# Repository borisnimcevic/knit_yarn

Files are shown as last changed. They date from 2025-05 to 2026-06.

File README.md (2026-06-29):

# Knit & Yarn Badge

A round PCB badge shaped like a ball of yarn with knitting needles. Six LEDs shine through the board face-down, lighting up the design from behind. Powered by a CR2032 coin cell; the brooch pin doubles as the power switch.

assembled badge

Designed in KiCad. Three badge variants and one SAO variant are included.

---

## Versions

| Folder | Description |
|---|---|
| `knit_yarn_badge_v1` | First prototype — through-hole battery holder |
| `knit_yarn_badge_v2` | SMD redesign, improved layout |
| `knit_yarn_badge_v3` | Current version — 0805 components, no vias |
| `knit_yarn_SAO` | Simple Add-On variant with 2×2 header |

---

## Bill of Materials (per badge)

| Reference | Component | Package | Qty |
|---|---|---|-----|
| D1–D6 | LED (any color) | 0805 | 6 |
| R1–R6 | Resistor | 0805 | 6 |
| BT1 | CR2032 coin cell holder | THT | 1 |
| SW1 | Brooch pin / SPST switch | custom | 1 |

> **Note:** Resistor values depend on your LED choice. For a standard 2V LED with a 3V CR2032 at ~10 mA per LED: R = (3V − 2V) / 10 mA = **100 Ω**.

---

## Ordering

Ready-to-order Gerber zips are in the [`order/`](./order/) folder:

- [`order/knit_yarn_badge_v1.zip`](./order/knit_yarn_badge_v1.zip)
- [`order/knit_yarn_badge_v2.zip`](./order/knit_yarn_badge_v2.zip)
- [`order/knit_yarn_badge_v3.zip`](./order/knit_yarn_badge_v3.zip) ← recommended
- [`order/knit_yarn_SAO.zip`](./order/knit_yarn_SAO.zip)

Upload the zip directly to your PCB fab (JLCPCB, PCBWay, etc.).

---

## Assembly

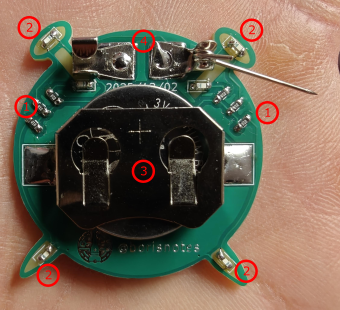
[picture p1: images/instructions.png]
instructions


1. **Resistors** — solder all 6 first (they're the lowest-profile component)
2. **LEDs** — place them **face down** (they shine into the PCB, not away from it)
   - The green mark on the LED points to the cathode, which aligns with the white edge on the footprint

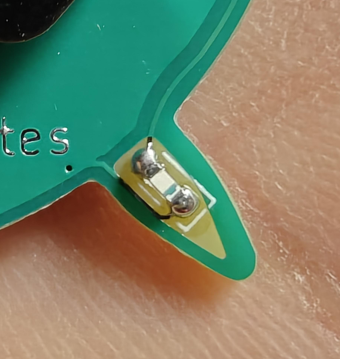
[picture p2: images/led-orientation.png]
led orientation
   

3. **Battery holder** — battery inserts from the back
4. **Brooch pin** — two-part assembly; use enough solder on both pads or the tension from clipping it may pop it loose

---

## SVG Source Files

The artwork SVGs used to generate the board graphics live in [`svg_source/`](./svg_source/).

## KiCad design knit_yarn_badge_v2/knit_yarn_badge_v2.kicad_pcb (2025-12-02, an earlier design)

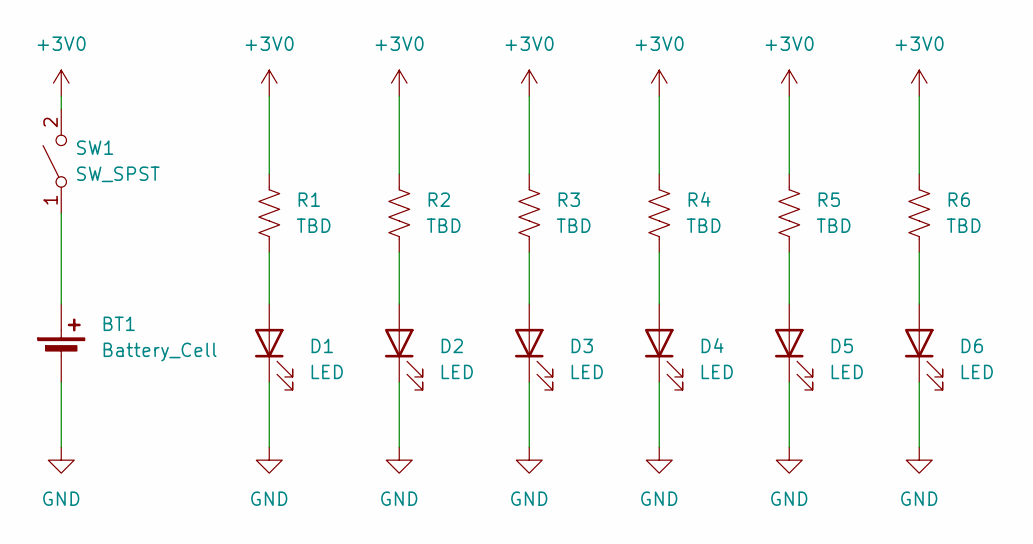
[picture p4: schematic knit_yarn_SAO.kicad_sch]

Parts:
BT1: Battery_Cell; BatteryHolder_Keystone_3002_1x2032
D1, D2, D3, D4, D5, D6: LED; LED_0603_1608Metric_Pad1.05x0.95mm_HandSolder
R1, R2, R3, R4, R5, R6: TBD; R_0603_1608Metric_Pad0.98x0.95mm_HandSolder
SW1: SW_SPST; brooch_SW_20mm

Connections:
+3V0: R1.1, R2.1, R3.1, R4.1, R5.1, R6.1, SW1.2 (B)
GND: BT1.2 (-), D1.1 (K), D2.1 (K), D3.1 (K), D4.1 (K), D5.1 (K), D6.1 (K)
unnamed: BT1.1 (+), SW1.1 (A)
unnamed: D1.2 (A), R1.2
unnamed: D2.2 (A), R2.2
unnamed: D3.2 (A), R3.2
unnamed: D4.2 (A), R4.2
unnamed: D5.2 (A), R5.2
unnamed: D6.2 (A), R6.2


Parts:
BT1: Battery_Cell; BatteryHolder_Keystone_3002_1x2032
D1, D2, D3, D4, D5, D6: LED; LED_0805_2012Metric_Pad1.15x1.40mm_HandSolder
R1, R2, R3, R4, R5, R6: TBD; R_0805_2012Metric_Pad1.20x1.40mm_HandSolder
SW1: SW_SPST; brooch_SW_20mm

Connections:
+3V0: R1.1, R2.1, R3.1, R4.1, R5.1, R6.1, SW1.2 (B)
GND: BT1.2 (-), D1.1 (K), D2.1 (K), D3.1 (K), D4.1 (K), D5.1 (K), D6.1 (K)
unnamed: BT1.1 (+), SW1.1 (A)
unnamed: D1.2 (A), R1.2
unnamed: D2.2 (A), R2.2
unnamed: D3.2 (A), R3.2
unnamed: D4.2 (A), R4.2
unnamed: D5.2 (A), R5.2
unnamed: D6.2 (A), R6.2

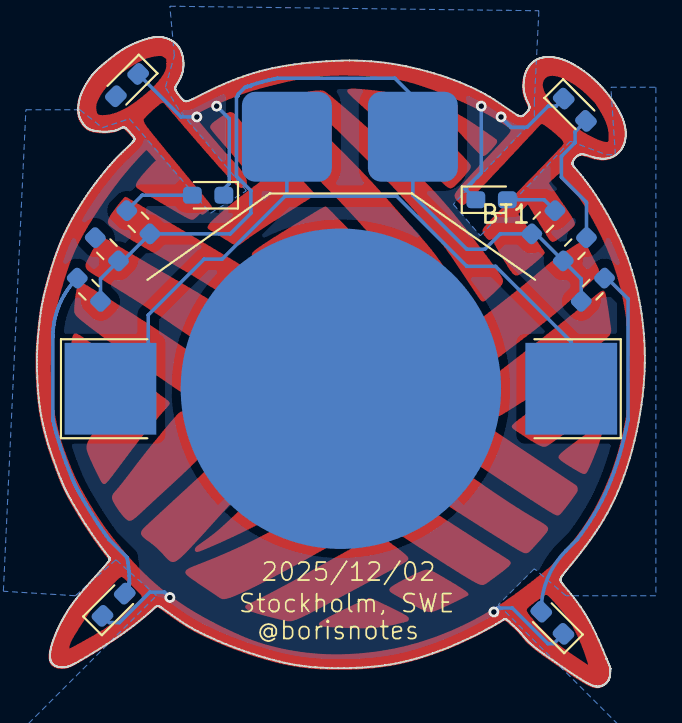
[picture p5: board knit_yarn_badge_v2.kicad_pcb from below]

Board: 2 copper layers, 33.8 x 36.1 mm, 14 parts (14 on the bottom side), 9 nets.

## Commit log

2025-05-12 Init repo.
    [knit_yarn.kicad_pcb, knit_yarn.kicad_sch]
2025-05-12 happy with graphics and added two more LEDs
    [knit_yarn.kicad_pcb, knit_yarn.kicad_sch]
2025-05-12 components in place
    [knit_yarn.kicad_pcb]
2025-05-12 back pour area
    [knit_yarn.kicad_pcb]
2025-05-12 fist draft
    [knit_yarn.kicad_pcb]
2025-05-12 one via
    [knit_yarn.kicad_pcb]
2025-05-12 add silk screen
    [knit_yarn.kicad_pcb]
2025-12-02 add inspo image
    [knit_yarn-B_Cu.gbr, knit_yarn-B_Mask.gbr, knit_yarn-B_Paste.gbr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]
2025-12-02 move v1 pcb to it's own folder
    [knit_yarn-B_Cu.gbr, knit_yarn-B_Mask.gbr, knit_yarn-B_Paste.gbr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]
2025-12-02 init v2 of the badge
    [knit_yarn_badge_v2.kicad_pcb, knit_yarn_badge_v2.kicad_sch]
2025-12-02 non movable components locked
    [knit_yarn_badge_v2.kicad_pcb, knit_yarn_badge_v2.kicad_sch]
2025-12-02 components arranged
    [knit_yarn_badge_v2.kicad_pcb, knit_yarn_badge_v2.kicad_sch]
2025-12-02 everything routed
    [knit_yarn_badge_v2.kicad_pcb]
2025-12-02 correct 3d model for the battery holder
    [knit_yarn_badge_v2.kicad_pcb]
2025-12-03 init SAO version
    [knit_yarn_SAO.kicad_sch]
2025-12-03 SAO connected and errors checked
    [knit_yarn_SAO.kicad_sch]
2025-12-04 generated gerbers
    [knit_yarn_SAO-B_Cu.gbr, knit_yarn_SAO-B_Mask.gbr, knit_yarn_SAO-B_Paste.gbr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]
2025-12-04 v2 generated gerbers
    [knit_yarn_badge_v2-B_Cu.gbr, knit_yarn_badge_v2-B_Mask.gbr, knit_yarn_badge_v2-B_Paste.gbr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]
2026-06-29 Add knit_yarn_badge_v3 based on v2 with 0805 components
    Upgraded all resistors and LEDs from 0603 to 0805 footprints for easier
    hand-soldering. Pad rotations updated to match component placement angles.
    Note: D1 and D2 are near the board edge — nudge them ~0.2mm inward in
    KiCad before ordering to ensure pads are fully within the board outline.
    [knit_yarn_badge_v3-B_Cu.gbr, knit_yarn_badge_v3-B_Mask.gbr, knit_yarn_badge_v3-B_Paste.gbr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]
2026-06-29 gerber for v3 ready
    [knit_yarn_badge_v3-B_Cu.gbr, knit_yarn_badge_v3-B_Mask.gbr, knit_yarn_badge_v3-B_Paste.gbr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]
2026-06-29 consolidate SVGs into svg_source/, remove per-version duplicates
    All SVG source files (thread, needles, copper, mask, layer, edge cuts,
    logo, etc.) were byte-for-byte identical across v1, v2, v3, and SAO
    folders. Moved the two files missing from svg_source/ there, then
    removed all 40 duplicates. KiCad projects are unaffected — the artwork
    is embedded as polygon data in the .kicad_mod files.
2026-06-29 add order/ folder with labeled gerbers, consolidate Edge.Cuts.png
    Gerber zips moved from per-version folders to order/ with consistent
    names (knit_yarn_badge_v1.zip, _v2, _v3, knit_yarn_SAO.zip).
    Identical Edge.Cuts.png copies removed; single copy kept as
    images/board_outline.png. .gitignore updated to block per-version
    SVGs, PNGs, and gerber zips from being re-added.
2026-06-29 rewrite README with project overview, BOM, versions, and ordering
    Replaced the assembly-only README with a full project description:
    what the badge is, version history table, BOM with component packages,
    ordering section pointing to order/, assembly instructions, and a note
    on the svg_source/ workflow.
